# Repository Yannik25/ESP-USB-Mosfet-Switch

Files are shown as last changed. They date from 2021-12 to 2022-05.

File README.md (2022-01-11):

# ESP USB/Mosfet Switch
 
 A small PCB, based on an ESP12E to switch USB or general 3.3V / 5V devices via Headers.
 Created with KiCad
 
## Current status: Ordered 
 
## Features

- 1. Multiple input selection
   - 12V/5V/3.3V via Headers
   - 5V via micro USB
   - 5V via USB-C

- 2. Multiple output selection
   - 12V/5V/3.3V via Headers (selectable via solderjumper)
   - 5V via USB-A 
   - 5V via USB-C
   
- 3. Read Current via INA226

- 4. Onboard WS2812B LED
	- control additional digital LEDs

## The Hardware:

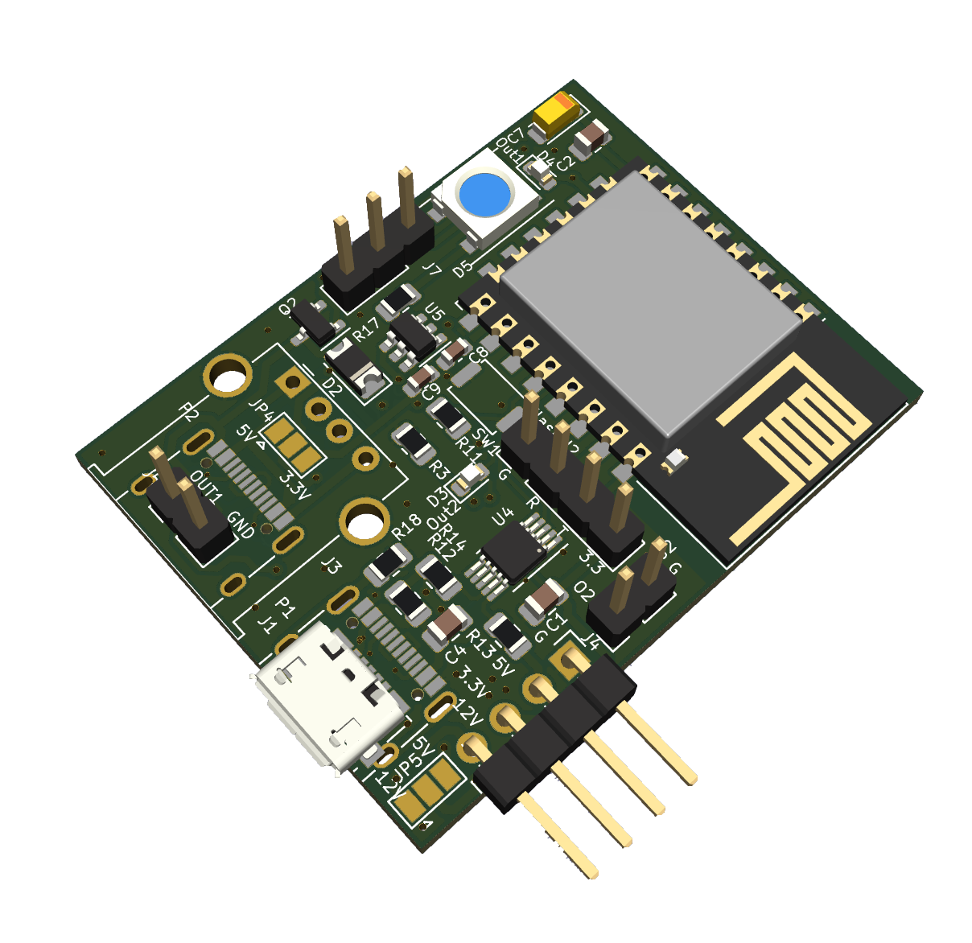
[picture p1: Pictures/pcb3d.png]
PCB 3D View


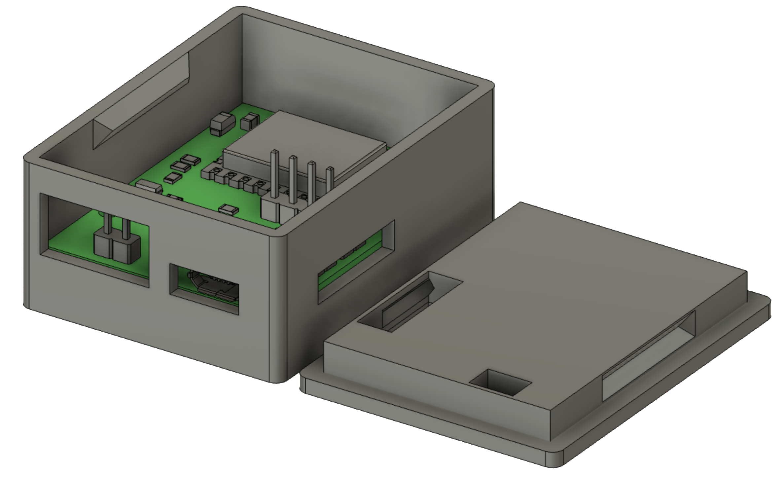
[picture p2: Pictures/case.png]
PCB Case


## Example configuration

```yaml
# Configuration for ESPHOME
```

## Contributions

Feel free to open Pull Requests here

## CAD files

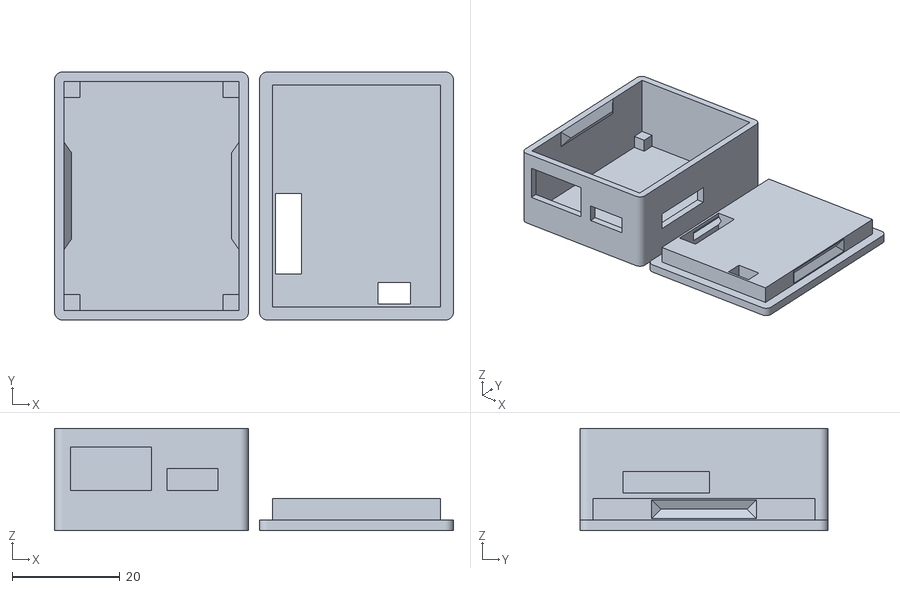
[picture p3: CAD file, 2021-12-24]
Models/espmosfetcase.stl
74.0 x 46.0 x 19.0

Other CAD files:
Models/espmosfetcase.f3d

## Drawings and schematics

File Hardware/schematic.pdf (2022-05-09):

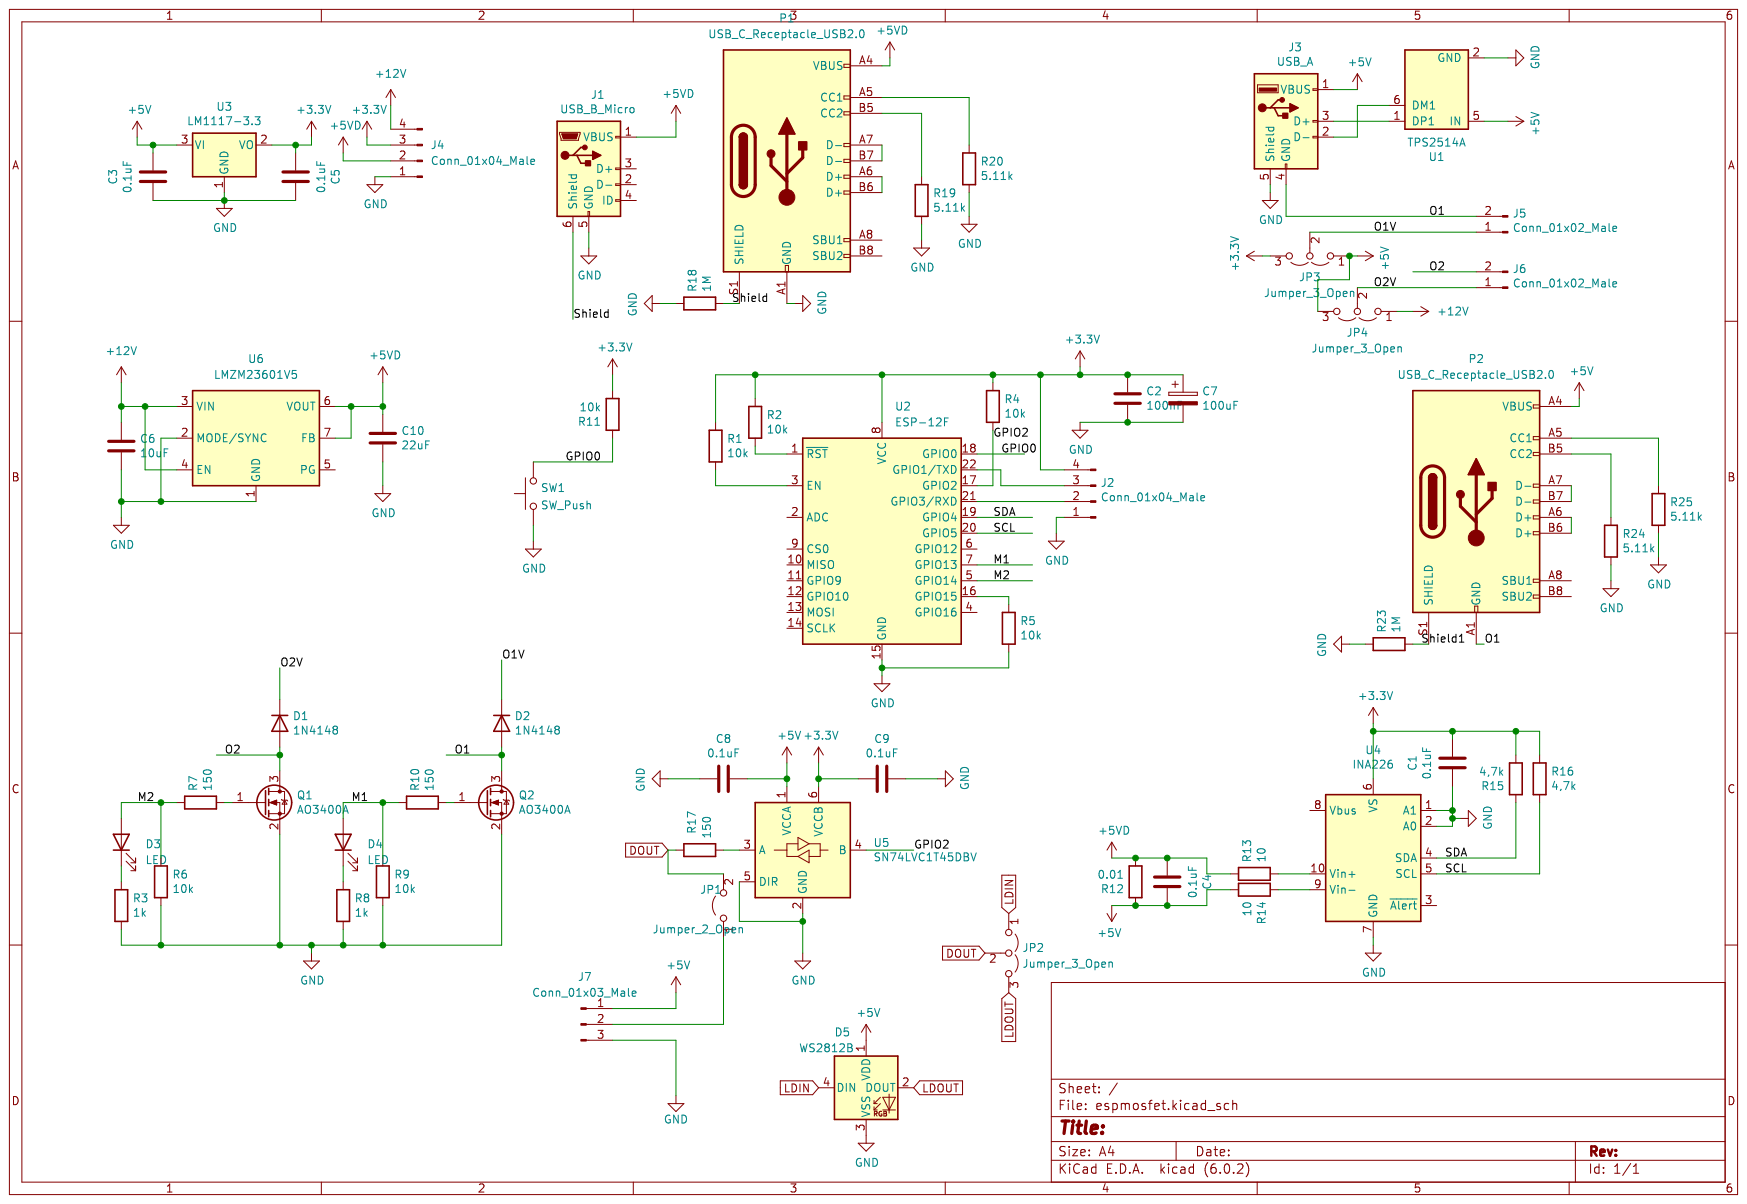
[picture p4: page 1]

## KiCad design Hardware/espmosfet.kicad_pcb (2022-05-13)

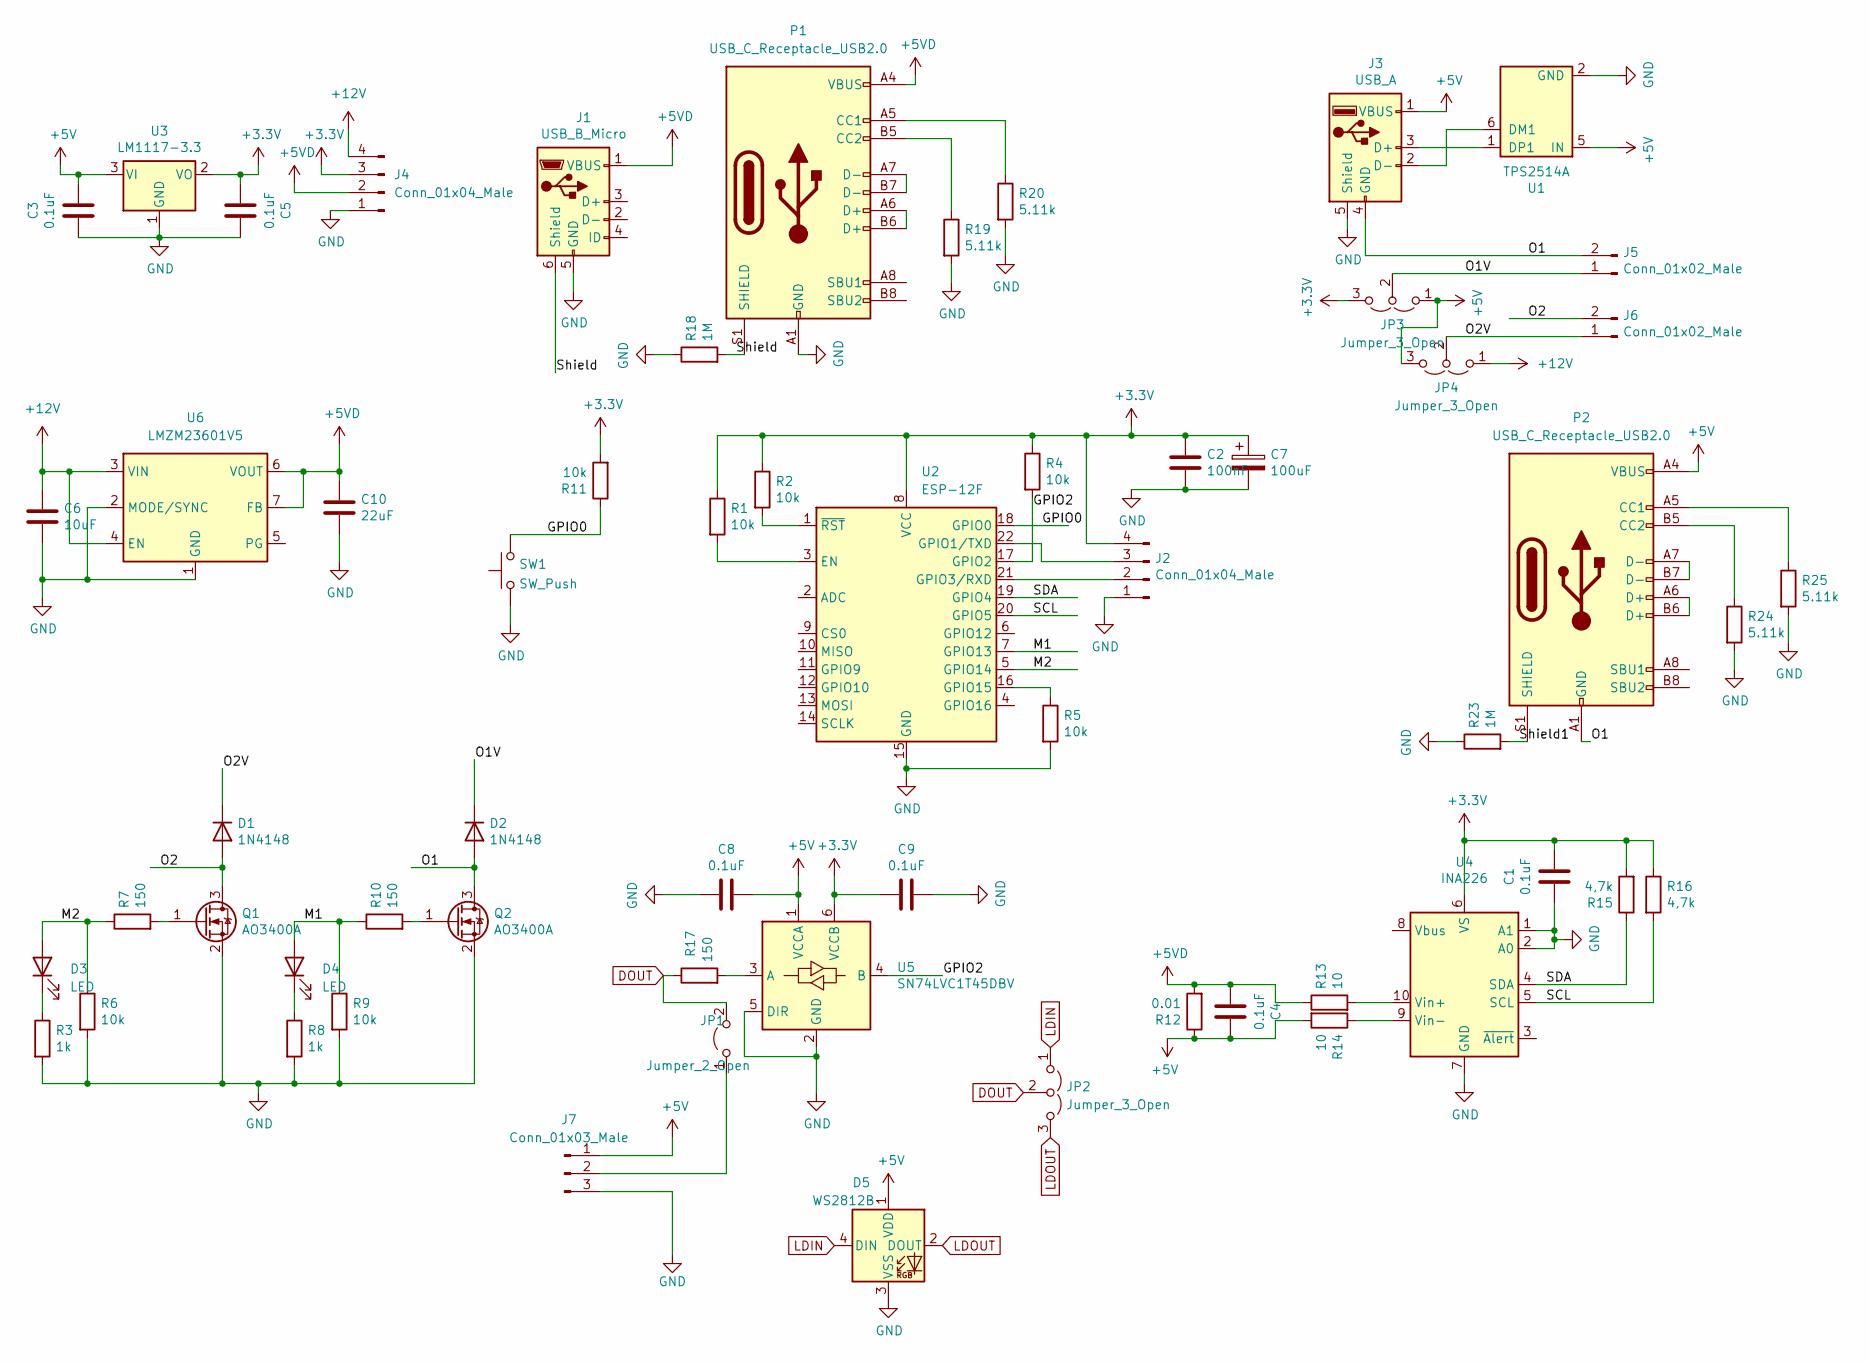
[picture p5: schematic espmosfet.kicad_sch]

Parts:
C1, C3, C4, C5: 0.1uF; C_0805_2012Metric
C2: 100nF; C_0805_2012Metric
C6: 10uF; C_0603_1608Metric
C7: 100uF; CP_EIA-3216-18_Kemet-A
C8, C9: 0.1uF; C_0603_1608Metric
C10: 22uF; C_0805_2012Metric
D1, D2: 1N4148; D_1206_3216Metric
D3, D4: LED; LED_0603_1608Metric
D5: WS2812B; LED_WS2812B_PLCC4_5.0x5.0mm_P3.2mm
J1: USB_B_Micro; USB_Micro-B_Molex_47346-0001
J2: Conn_01x04_Male; PinHeader_1x04_P2.54mm_Vertical
J3: USB_A; USB_A_Stewart_SS-52100-001_Horizontal
J4: Conn_01x04_Male; PinHeader_1x04_P2.54mm_Horizontal
J5, J6: Conn_01x02_Male; PinHeader_1x02_P2.54mm_Vertical
J7: Conn_01x03_Male; PinHeader_1x03_P2.54mm_Vertical
JP1: Jumper_2_Open; SolderJumper-2_P1.3mm_Open_Pad1.0x1.5mm
JP2, JP3, JP4: Jumper_3_Open; SolderJumper-3_P1.3mm_Open_Pad1.0x1.5mm
P1, P2: USB_C_Receptacle_USB2.0; USB_C_Receptacle_XKB_U262-16XN-4BVC11
Q1, Q2: AO3400A; SOT-23
R1, R2, R4, R5, R6, R9, R11: 10k; R_0805_2012Metric
R3, R8: 1k; R_0805_2012Metric
R7, R10, R17: 150; R_0805_2012Metric
R12: 0.01; R_0805_2012Metric
R13, R14: 10; R_0805_2012Metric
R15, R16: 4,7k; R_0805_2012Metric
R18, R23: 1M; R_0805_2012Metric
R19, R20, R24, R25: 5.11k; R_0603_1608Metric
SW1: SW_Push; SW_Push_SPST_NO_Alps_SKRK
U1: TPS2514A; SOT-23-6
U2: ESP-12F; ESP-12E
U3: LM1117-3.3; SOT-223
U4: INA226; VSSOP-10_3x3mm_P0.5mm
U5: SN74LVC1T45DBV; SOT-23-6
U6: LMZM23601V5; Texas_SIL0010A_MicroSiP-10-1EP_3.8x3mm_P0.6mm_EP0.7x2.9mm_T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

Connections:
+3V3: C1.1, C2.1, C5.2, C7.1, C9.2, J2.4, J4.3, JP3.3 (B), R1.1, R2.1, R4.1, R11.2, R15.2, R16.1, U2.8 (VCC), U3.2 (VO), U4.6 (VS), U5.6 (VCCB)
+5V: C3.1, C4.1, C8.1, D5.1 (VDD), J3.1 (VBUS), J7.1, JP3.1 (A), JP4.3 (B), P2.A4 (VBUS), P2.A9 (VBUS), P2.B4 (VBUS), P2.B9 (VBUS), R12.1, R14.2, U1.5 (IN), U3.3 (VI), U5.1 (VCCA)
+5VD: C4.2, C10.1, J1.1 (VBUS), J4.2, P1.A4 (VBUS), P1.A9 (VBUS), P1.B4 (VBUS), P1.B9 (VBUS), R12.2, R13.1, U6.6 (VOUT), U6.7 (FB)
+12V: C6.1, J4.4, JP4.1 (A), U6.3 (VIN), U6.4 (EN)
/GPIO0: R11.1, SW1.2, U2.18 (GPIO0)
/GPIO2: R4.2, U2.17 (GPIO2), U5.4 (B)
/M1: D4.2 (A), R9.1, R10.1, U2.7 (GPIO13)
/M2: D3.2 (A), R6.1, R7.1, U2.5 (GPIO14)
/O1: D2.2 (A), J3.4 (GND), J5.2, P2.A1 (GND), P2.A12 (GND), P2.B1 (GND), P2.B12 (GND), Q2.3 (D)
/O1V: D2.1 (K), J5.1, JP3.2 (C)
/O2: D1.2 (A), J6.2, Q1.3 (D)
/O2V: D1.1 (K), J6.1, JP4.2 (C)
/SCL: R16.2, U2.20 (GPIO5), U4.5 (SCL)
/SDA: R15.1, U2.19 (GPIO4), U4.4 (SDA)
/Shield: J1.6 (Shield), P1.S1 (SHIELD), R18.2
/Shield1: P2.S1 (SHIELD), R23.2
DOUT: JP1.2 (B), JP2.2 (C), R17.1
GND: C1.2, C2.2, C3.2, C5.1, C6.2, C7.2, C8.2, C9.1, C10.2, D5.3 (VSS), J1.5 (GND), J2.1, J3.5 (Shield), J4.1, J7.3, P1.A1 (GND), P1.A12 (GND), P1.B1 (GND), P1.B12 (GND), Q1.2 (S), Q2.2 (S), R3.2, R5.2, R6.2, R8.2, R9.2, R18.1, R19.2, R20.2, R23.1, R24.2, R25.2, SW1.1, U1.2 (GND), U2.15 (GND), U3.1 (GND), U4.1 (A1), U4.2 (A0), U4.7 (GND), U5.2 (GND), U5.5 (DIR), U6.1 (GND), U6.2 (MODE/SYNC), U6.11 (GND)
LDIN: D5.4 (DIN), JP2.1 (A)
LDOUT: D5.2 (DOUT), JP2.3 (B)
unnamed: D3.1 (K), R3.1
unnamed: D4.1 (K), R8.1
unnamed: J2.2, U2.21 (GPIO3/RXD)
unnamed: J2.3, U2.22 (GPIO1/TXD)
unnamed: J3.2 (D-), U1.6 (DM1)
unnamed: J3.3 (D+), U1.1 (DP1)
unnamed: J7.2, JP1.1 (A)
unnamed: P1.A5 (CC1), R20.1
unnamed: P1.A6 (D+), P1.B6 (D+)
unnamed: P1.A7 (D-), P1.B7 (D-)
unnamed: P1.B5 (CC2), R19.1
unnamed: P2.A5 (CC1), R25.1
unnamed: P2.A6 (D+), P2.B6 (D+)
unnamed: P2.A7 (D-), P2.B7 (D-)
unnamed: P2.B5 (CC2), R24.1
unnamed: Q1.1 (G), R7.2
unnamed: Q2.1 (G), R10.2
unnamed: R1.2, U2.3 (EN)
unnamed: R2.2, U2.1 (~RST)
unnamed: R5.1, U2.16 (GPIO15)
unnamed: R13.2, U4.10 (Vin+)
unnamed: R14.1, U4.9 (Vin-)
unnamed: R17.2, U5.3 (A)

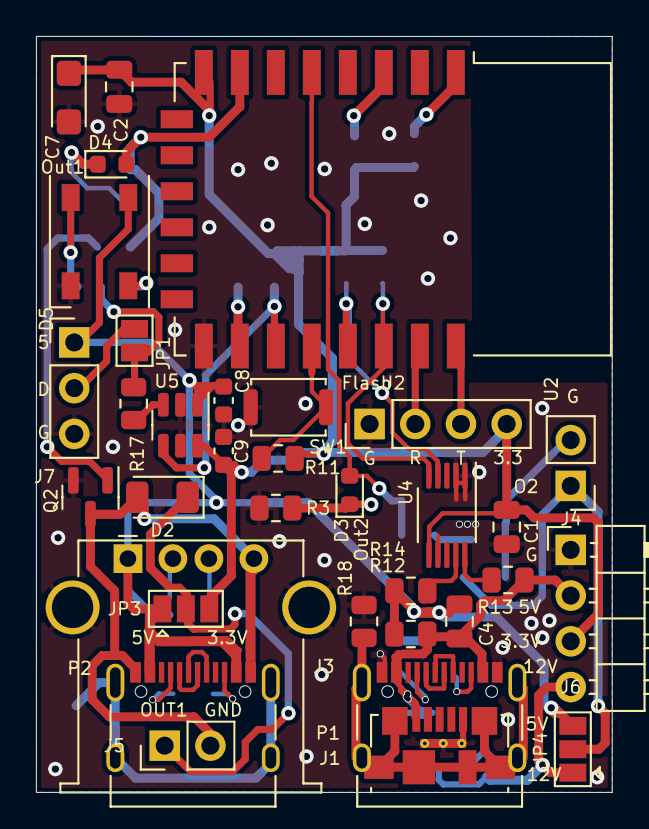
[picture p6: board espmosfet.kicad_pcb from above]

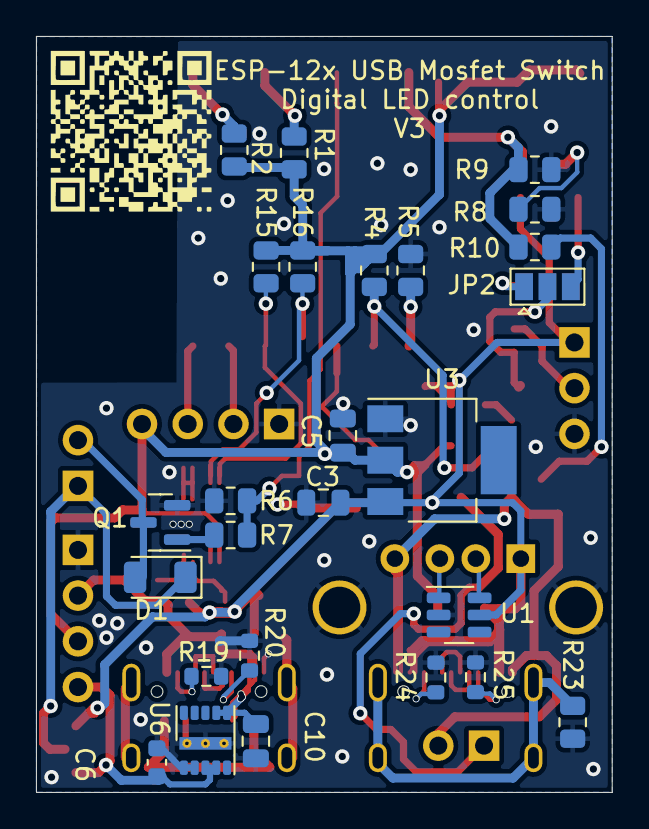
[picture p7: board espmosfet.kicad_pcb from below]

Board: 2 copper layers, 32.0 x 42.0 mm, 60 parts (26 on the bottom side), 43 nets.

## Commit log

2021-12-14 add initial hardware version
    [espmosfet.kicad_pcb, espmosfet.sch]
2021-12-22 add information, pictures and models
    [espmosfetcase.stl]
2021-12-24 fix case size
    [espmosfetcase.f3d, espmosfetcase.stl]
2022-01-10 update sch and pcb, fix mosfet, add 12V option, add digital led pins
    [espmosfet.kicad_pcb, espmosfet.kicad_sch]
2022-01-10 add USB-C input
    [espmosfet.kicad_pcb, espmosfet.kicad_sch]
2022-01-11 add ws2812b on board, add USB-C Output
    [espmosfet.kicad_pcb, espmosfet.kicad_sch]
2022-01-11 add schematics pdf
2022-01-11 update to V2 Version
    [espmosfet.kicad_pcb, espmosfet.kicad_sch]
2022-01-11 adjust Readme
    [espmosfet.kicad_pcb, espmosfet.kicad_sch]
2022-02-04 add gerber
2022-05-09 fix ws2812b pinout, change to open jumpers
    [espmosfet.kicad_pcb, espmosfet.kicad_sch]
2022-05-13 update gerber
    [espmosfet.kicad_pcb]
